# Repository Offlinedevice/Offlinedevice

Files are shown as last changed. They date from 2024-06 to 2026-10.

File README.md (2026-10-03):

# Offline device

Offline device is a hardware device that runs on a Raspberry OS (Linux based) operating system. It can be built with standard components found in the Internet and all the plastic parts can be printed on a 3D-printer.

The Graphical User Interface is written in Python 3 (GUIApp.py).

Follow on Nostr: [npub1srsejseljs22kg580hvcqs3uj3l0fwh8tamhaumdu2gfn3sxs3lskp3chs](https://primal.net/p/npub1srsejseljs22kg580hvcqs3uj3l0fwh8tamhaumdu2gfn3sxs3lskp3chs)

## Features

- [x] Create strong encryption keys offline (GnuPG)
- [x] Use hardware key (NFC Forum Type 2 Tag) for login (optional) 
- [x] Create Bitcoin wallets and Bitcoin Multisig wallets with your own true randomness
- [x] Do offline signing and key management with "Web of trust" -model
- [x] Fully open source (APGLv2)
- [x] Store important files in an encrypted archive (RSA encryption acc. to RFC 4880)
- [x] Encrypt/decrypt and sign files or messages in a secure offline way 
- [x] Decrypt files or messages and check its signature (GnuPG)
- [x] Backup and restore function, including complete system cloning
- [x] Add Bitcoin wallets created from Jade hardware wallet or others for air-gapped transaction signing (BIP84)
- [x] Inheritance package
- [x] Wallet transactions statements 
- [x] Sign Bitcoin wallet messages to prove ovnership of wallet 
- [x] Encrypted password manager
- [x] Generate and manage your own digital ID's (Web of Trust, OpenPGP)
- [x] Generate your own Nostr Keys
- [x] Transfer a Nostr private Key to a Nostr Signing Device
- [x] Validate others digital ID's and keys (standard (RFC 4880)
- [x] Store Bolt cards data for accessing load links (lighning Bitcoin), programming and resetting cards
- [x] Option for strong password generation (also with user entropy)

## Using the Offine device

Connect the Offline device with cables to a monitor, a keyboard and a mouse. It supports multiple account on the same device. Import or generate GPG keys without being connected to the Internet. During setup a backup USB- device is created. The Offline device facilitates complete privacy and unbreakable encryption for sensitive data and also provides a mechanism for securely send and receive data over the Internet. Others features include Bitcoin wallet generation/storage and transaction signing.

### Guides

* [Getting started guide](https://github.com/Offlinedevice/Offlinedevice/blob/057806e96a671aa06b3eac34bdbc17a77e54d67b/help/getstartedHelp.txt)
* [GPG guide](https://github.com/Offlinedevice/Offlinedevice/blob/e34fb841eac5e7634a74db3f75f62b0f8ab91fca/help/gpgHelp.txt)
* [Yubikey guide](https://github.com/Offlinedevice/project/blob/291037e6e33de97521e22a7abb742123ab7c2843/help/yubikeyHelp.txt)
* [Secure archive guide](https://github.com/Offlinedevice/project/blob/291037e6e33de97521e22a7abb742123ab7c2843/help/securearchiveHelp.txt)
* [Digital ID guide](https://github.com/Offlinedevice/project/blob/291037e6e33de97521e22a7abb742123ab7c2843/help/digitalIDHelp.txt)
* [Bolt card guide](https://github.com/Offlinedevice/Offlinedevice/blob/e34fb841eac5e7634a74db3f75f62b0f8ab91fca/help/boltcardHelp.txt)

## Start here

### Build hardware
Build the Offline device using common parts. See [Getting started guide](https://github.com/Offlinedevice/Offlinedevice/blob/057806e96a671aa06b3eac34bdbc17a77e54d67b/help/getstartedHelp.txt)

### 3D- print parts 
Print the plastic parts you need (for the Pi2W version):
* [Base part](https://github.com/Offlinedevice/Offlinedevice/blob/924e57b3c216d11b1677c1a1f53b54e1da3e4c15/3D/PiZero2W/case/PIzeroBoxRoundedCamera-Body.stl)
* [Lid for build with camera model 1/2](https://github.com/Offlinedevice/Offlinedevice/blob/924e57b3c216d11b1677c1a1f53b54e1da3e4c15/3D/PiZero2W/case/LidPIzeroBoxCamera1_and_2_RFID_high-Body.stl)
* [Alt. lid for camera model 3 (12 MP and auto focus lens)](https://github.com/Offlinedevice/Offlinedevice/blob/924e57b3c216d11b1677c1a1f53b54e1da3e4c15/3D/PiZero2W/case/LidPIzeroBoxCamera3_RFID_high-Body.stl)
* [LED guide](https://github.com/Offlinedevice/Offlinedevice/blob/924e57b3c216d11b1677c1a1f53b54e1da3e4c15/3D/PiZero2W/case/LEDguide_high-Body.stl)

See also the folder for other featured 3D- parts (such as the Pi 5).

For printing the Docking station (Raspberry Pi Zero 2W) check out the 3D- files [here](https://github.com/Offlinedevice/Offlinedevice/tree/924e57b3c216d11b1677c1a1f53b54e1da3e4c15/3D/PiZero2W/Dock) and for Pi 5 [here](https://github.com/Offlinedevice/Offlinedevice/tree/924e57b3c216d11b1677c1a1f53b54e1da3e4c15/3D/Pi5/Dock).

### Download and burn image
Download the latest full image and verify it with the corresponding signature. Select the one suitable for your system. Latest update files are found [here](https://github.com/Offlinedevice/Offlinedevice/tree/main/code/GUIApp0_5_7).
* [Raspberry Pi 2 W Image (1,57 gb)](https://www.mediafire.com/file/e7imedgw5ff8n8o/GUIApp0_5_8_Pi2W.img.gz/file)
* [Raspberry Pi 2 W Image Signature](https://www.mediafire.com/file/aozdl05zw8l33cv/GUIApp0_5_8_Pi2W.img.gz.sig/file)
* [Raspberry Pi 5 Image (2,38 gb)](https://www.mediafire.com/file/ete95xyzsxav7um/GUIApp0_5_8_Pi5.img.gz/file) 
* [Raspberry Pi 5 Image Signature](https://www.mediafire.com/file/gw801u4gvd1emua/GUIApp0_5_8_Pi5.img.gz.sig/file)
 
Make sure you have the correct public key (see below) imported to your local keychain. Then place the two downloaded files (the signature and the image) in the same directory and run command: gpg --verify signature_files_name.sig image_files_name.img.gz (insert the real name for the files..).

Then burn it to a microSD-card (min 32 gb) with BalenaEtcher (recommended) or the Raspberry Pi Imager. Please note that it might be necessary to restart the device after initial power ON for it to start.

### Or, install the software yourself
You can choose to install the operating system, programs and libraries yourself. See details in the "Getting started"- document (not updated). 

## Personalized accounts
Change the look and feel of your account. 

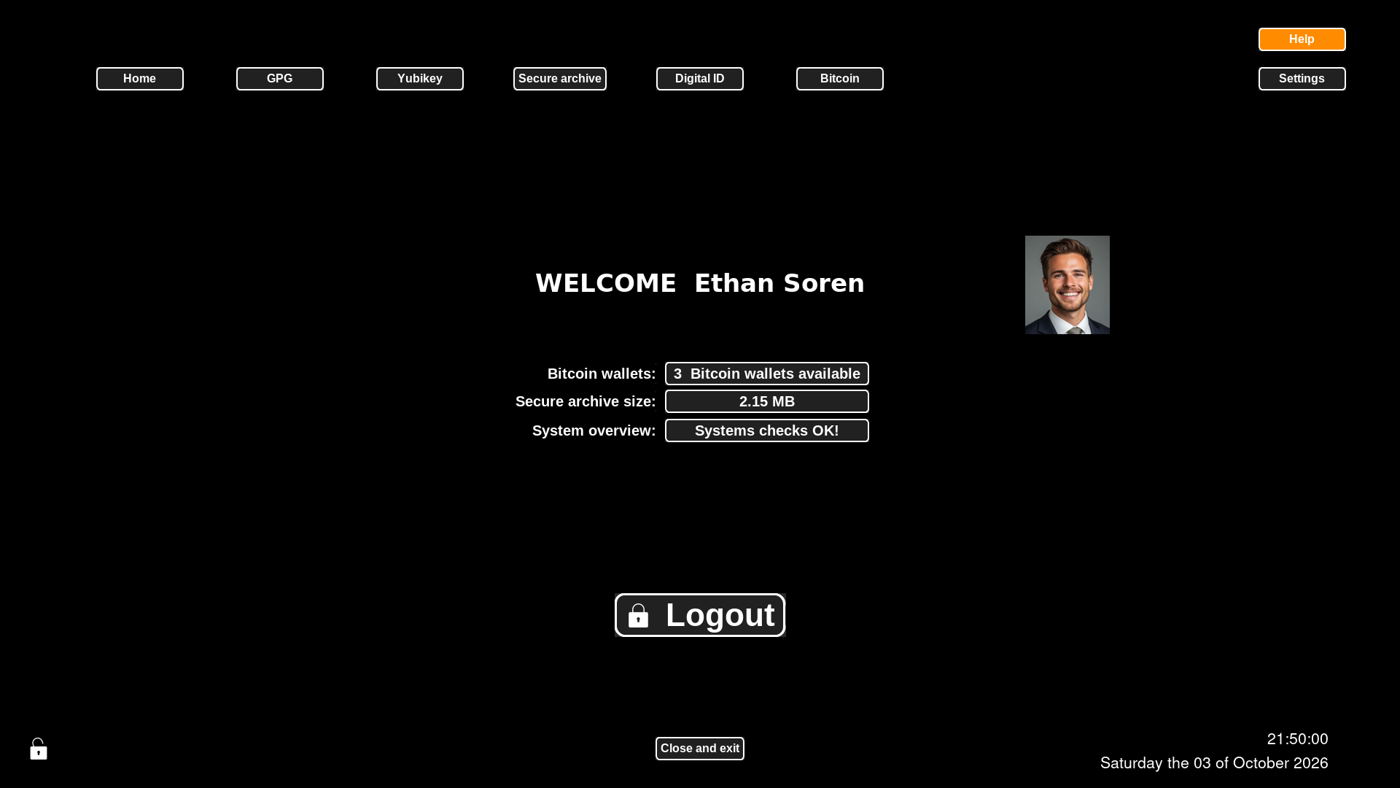
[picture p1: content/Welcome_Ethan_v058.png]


## Manage encryption keys
The device allows you to create your own keys in a secure (and offline) enviroment. Then use and manage the encryption keys on your device. Adding signatures, signing other keys and documents, encrypting and decrypting etc. 

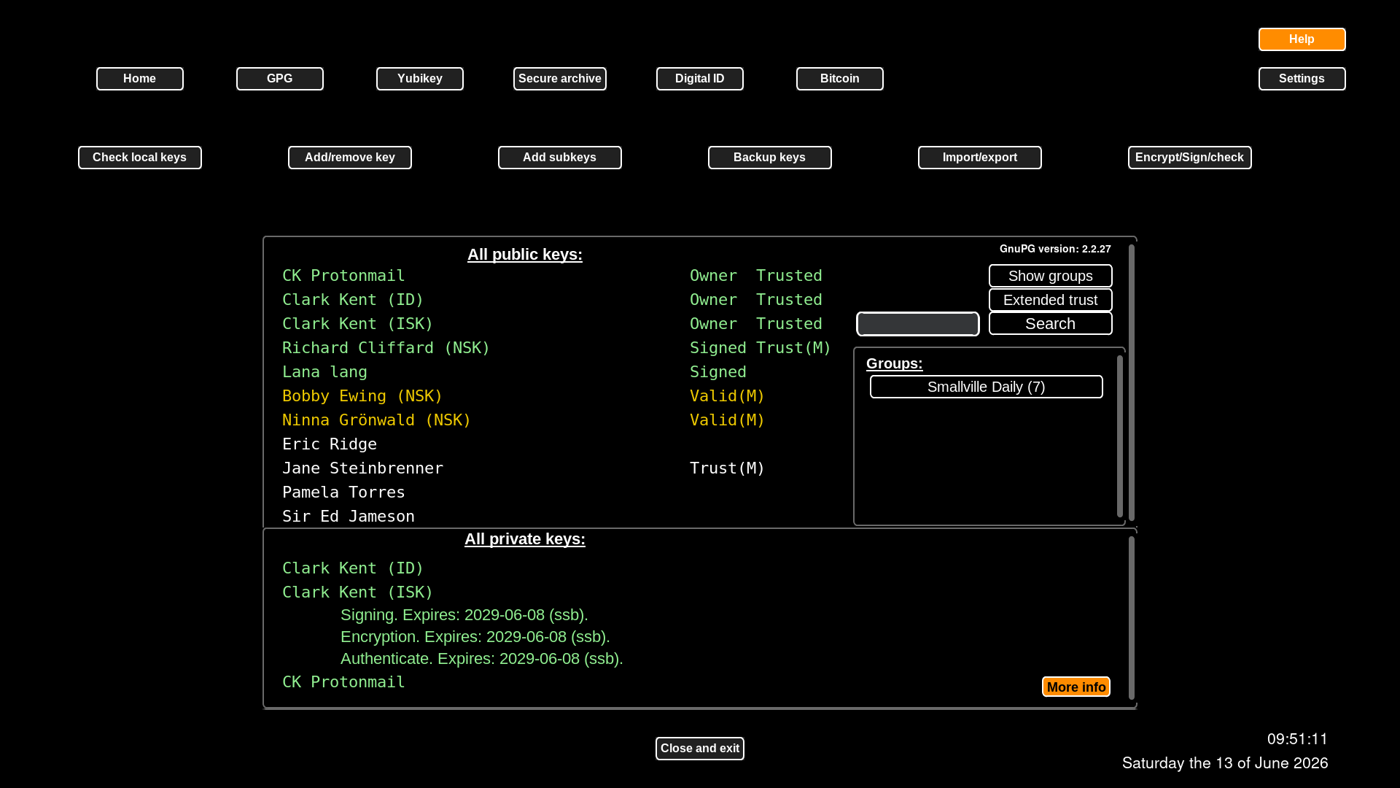
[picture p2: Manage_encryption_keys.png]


## Add and create Bitcoin wallets and Multisig wallets
A wallet can be generated by a trusted hardware wallet such as Blockstream Jade and then inported to get air-gapped functionality while the keys are encrypted on the Offline device. Or, you can create your own keys (seed words) with randomness from dice throws etc.

## Bitcoin Multisig wallets
Create your own multisig signing keys and wallets. Share wallets and signing keys using PGP-encrypted and signed messaging. Also share transactions (request signatures and receive signed transactions back) using PGP-encrypted and signed messaging.

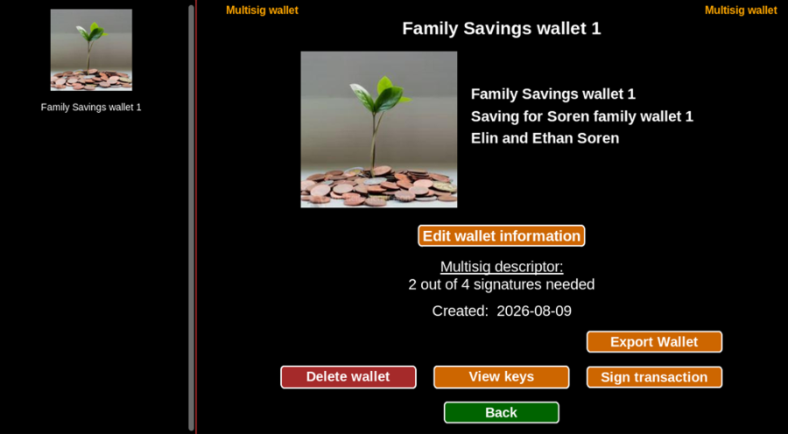
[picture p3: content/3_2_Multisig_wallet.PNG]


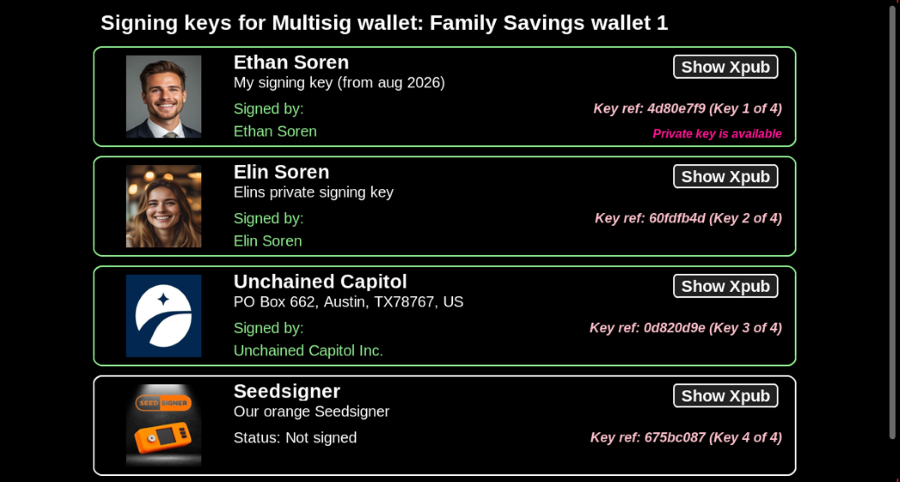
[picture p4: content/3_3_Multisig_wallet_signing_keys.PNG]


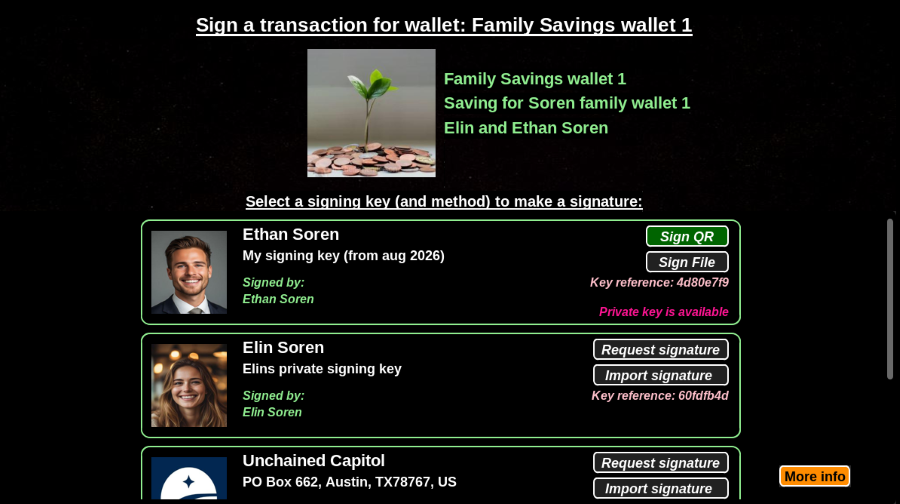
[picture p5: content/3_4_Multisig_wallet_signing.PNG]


## Digital IDs
Controlling your own digital ID is as important as controlling your own digital money. The Offline device gives an easy way to create IDs and encrypted files that can be uploaded to public keyservers around the word. Including picture ID/key and corporate ID. 

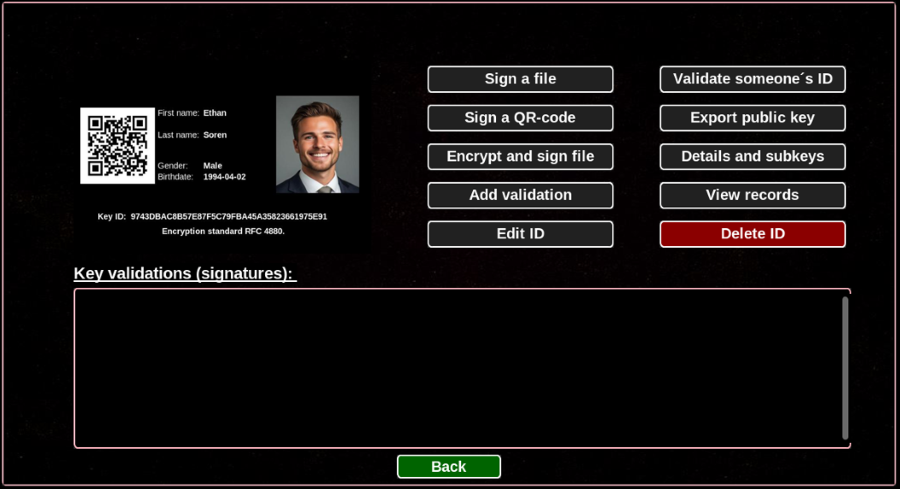
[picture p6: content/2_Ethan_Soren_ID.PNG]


### Update GUI
Make sure you are running the latest graphical interface, GUIApp.py. Download the latest tar- file from the download section and select "settings -> Update software" on the Offline device. 

## Locales
Using a Raspberry Pi keyboard and mouse supports in getting the Locales (correct layout of keys etc.). Always set the correct time and date before staring to use the device. This is important for encryption key generation and date/time stamps. 

## Release + Commit Verification
All releases and commits as of June 28, 2024 are signed by key [BEF873B4691EB2C24E399445FE86F26704C3F74APubKey.asc](https://github.com/Offlinedevice/Offlinedevice/blob/159a1fd89408b5ca1548024ed3b90ddb94b2da3f/code/BEF873B4691EB2C24E399445FE86F26704C3F74APubKey.asc).

### Past Keys
None.

## Donations
If you'd like to help us with the cost of running the Offline device project you can send a payment to us via our BTC address bc1qd0ufcz2xptanlgj2xagzpz46cqdwkvlu69m2vs.

Thank you.

## License

Distributed under the GNU Affero General Public License (AGPL v2). See [LICENSE file](LICENSE).

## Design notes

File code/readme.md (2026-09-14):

## Code for Raspberry Pi 2 W and Raspberry Pi 5:
### Raspberry Pi Zero 2 W configuration:
 - Raspberry Pi Zero 2W
 - RTC DS1307
 - RC522 RFID module
 - Pi camera module 1, 2 or 3

### Wiring schematics Raspberry Pi Zero 2 W:
Make sure to use the correct Lid as the camera modules differ in height. Use 2 mm screws with the right lenght. 

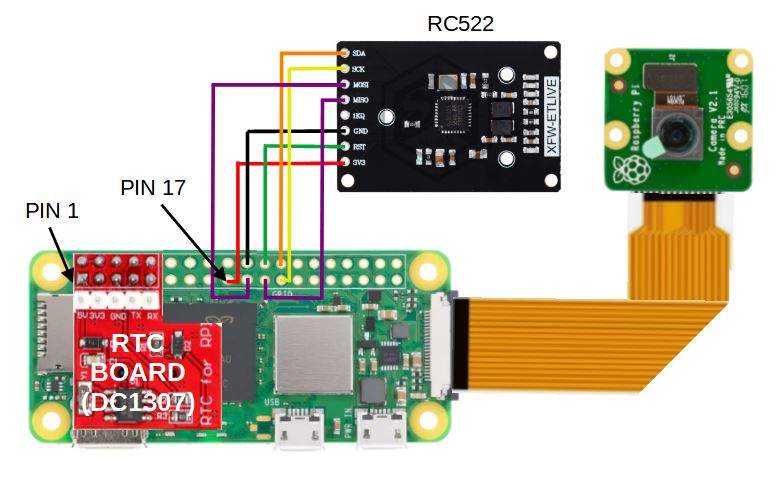
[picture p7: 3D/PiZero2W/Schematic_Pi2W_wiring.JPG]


### Raspberry Pi 5 configuration:
 - Raspberry Pi 5 (min 1 GB RAM)
 - RTC battery
 - PN532 RFID module V3
 - 5V 3007 Fan PWM Speed Adjustable CPU Cooling fan
 - LED, RGB model WS2812D
 - Cable for camera, MIPI 22-pin to FPC 15-pin (CSI), 8 cm
 - Lithium RTC clock battery, 3 V
 - Pi camera module 1, 2 or 3

 - ### Wiring schematics Raspberry Pi 5
Make sure to use the correct Lid as the camera modules differ in height. Use 2 mm screws with the right lenght.

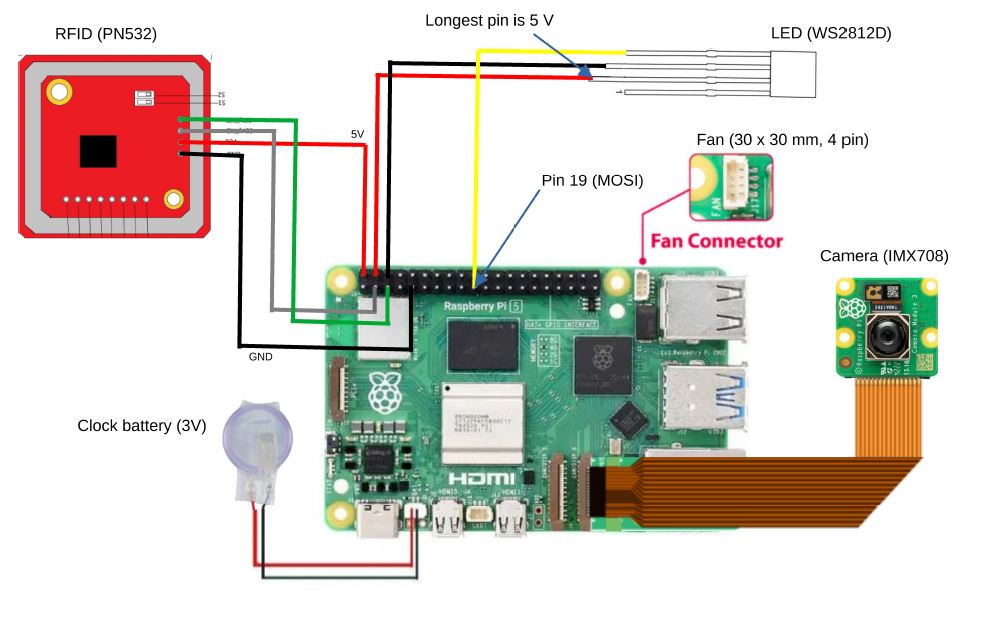
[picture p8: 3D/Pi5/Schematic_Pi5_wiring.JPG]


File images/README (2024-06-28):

# Files that need to be in Offline devices directory /home/user1/venvpython/images.

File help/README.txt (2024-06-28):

# All help files for the Offline device.

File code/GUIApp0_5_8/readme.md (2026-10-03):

## GUI app for the Offline device. This release can be installed using the following:

### For Raspberry Pi Zero 2 W: GUIApp_0_5_8_Pi2W.tar.gz. The full Image (v0.5.7) or later needs to installed.
### For Raspberry Pi 5: GUIApp_0_5_8_Pi5.tar.gz. The full Image (v0.5.7) or later needs to installed.
##

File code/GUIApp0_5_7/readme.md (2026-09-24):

## GUI app for the Offline device. This release can be installed using the following:

### For Raspberry Pi Zero 2 W: GUIApp_0_5_7_Pi2W.tar.gz. The full Image (v0.5.7) or later needs to installed.
### For Raspberry Pi 5: GUIApp_0_5_7_Pi5.tar.gz. The full Image (v0.5.7) or later needs to installed.
##

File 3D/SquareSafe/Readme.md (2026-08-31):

## Hardware safe for Offline device and/or other devices:
Safe details:
 - Based on a padlock with extra long shackle such as ABUS 64ti/50hb60-150.
 - Internal plastic parts are printed using high strenght material such as PETG-CF or PA6-CF20 etc for best performance.
 - Internal storage compartment have four options: two for a vertical mounted safes and two for horizontally mounted safes.
 - See also assembly schematics and technical drawings for more details. 

## Using a hardware safe
The safe can't protect the stored content from heat during a fire or from a thief using heavy equipment or mashinery. Instead it protects from manipulation (planting key loggers and other spyware).

Outer case can be aluminium, steel or simply 3D printed plasic (see [SquareSafe tube drawing](https://github.com/Offlinedevice/Offlinedevice/blob/ef2869bde410553fd2b8278cb0528959d3572997/3D/SquareSafe/SquareSafe%20tube%20drawing.pdf)).

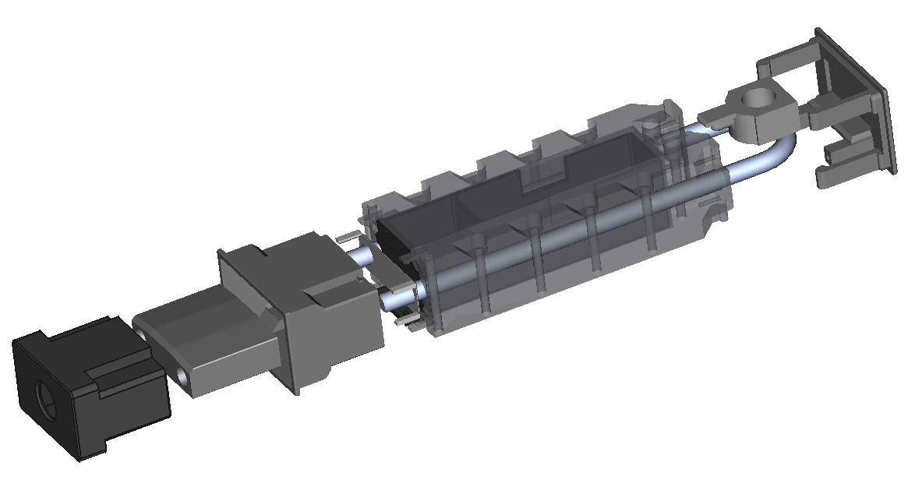
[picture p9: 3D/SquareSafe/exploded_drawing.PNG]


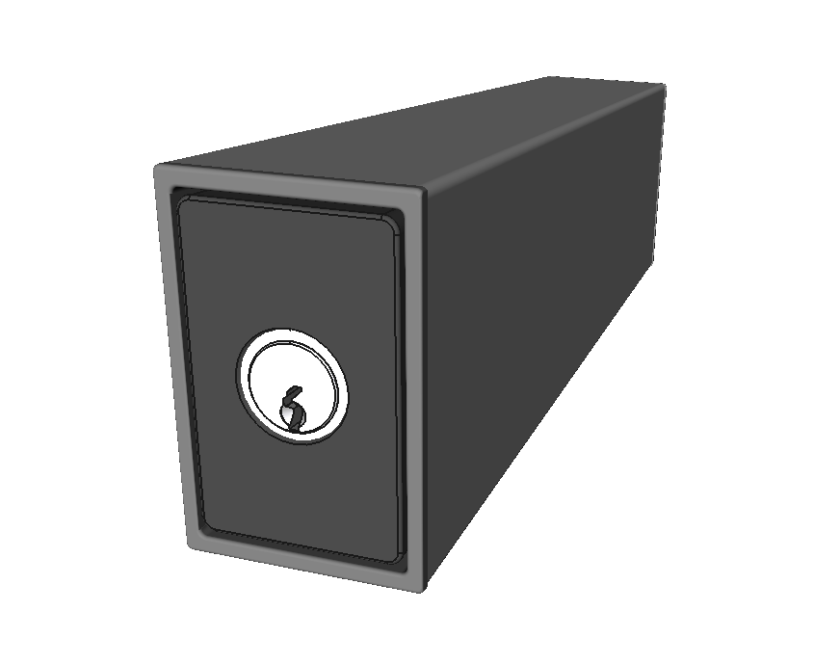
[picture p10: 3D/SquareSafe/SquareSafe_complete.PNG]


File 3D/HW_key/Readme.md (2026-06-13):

## Hardware key for Offline device:
Key contains:
 - NTAG210q or similar NFC Forum Type 2 tag (min 48 bytes of memory and max dimensions 12 x 19 mm)
 - LED-chip with antenna for luminate when in proximity to RF-field.

## Using the HW-key to unlock account
Select add HW-key during account creation (or later on). Create the new account with a truly random base58 password (select "use strong password" and follwo the instructions). 
Then create a truly random salt (secret) also select a easy to remember PIN. Hold the key over the device to write the salt/secret to NTAG-memory. 
Now when the account is encrypted (during shudown/logout) both the HW-keys and the "strong password" will be use to encrypt your secret data. 
So during next login you can use the either the long base58 password the you you created with your own randomness (more difficult) or you can use one of your HW-keys by holding it close to the reader and type in your PIN (if any). 
The passphrase used to decrypt the account is then hashed (calculated) from the salt+keys serial number+PIN using a proof-of-work algorithm.

If using LED-chip inside key use transparent PETG-filament or similar for a nice effect.
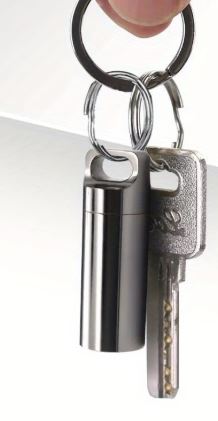
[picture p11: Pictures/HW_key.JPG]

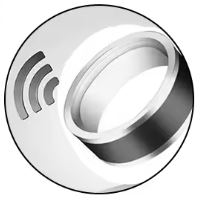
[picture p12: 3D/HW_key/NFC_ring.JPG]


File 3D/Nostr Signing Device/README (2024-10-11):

# Files for printing a Nostr Signing Device (NSD), using a 3D- printer.

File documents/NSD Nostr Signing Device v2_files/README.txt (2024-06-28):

# All files that goes in directory "Documents" on the Offline device.

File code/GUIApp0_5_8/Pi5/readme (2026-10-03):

A full image that can be burned to a microSD- card with minimum 32 gb storage as linked on the Project main page. Note, the image is only operational with specified hardware: Raspberry Pi 5, Rechargeable real time clock battery, RFID module PN532 (optional) and a PI camera module (ov5647/imx219/imx708)
Update to version 0.5.8 can be done with GUIApp0_5_8_Pi5.tar.gz (needs the the full image version 0.5.7 or later to be installed first).

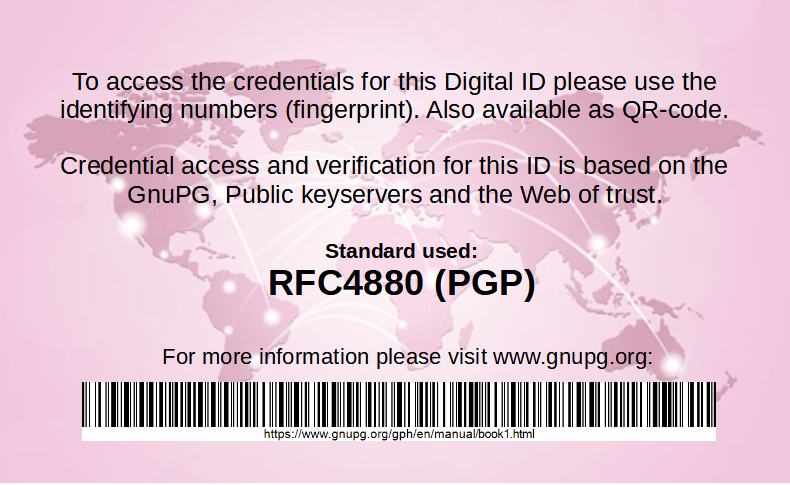
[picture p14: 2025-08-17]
images/ID_map_back.png

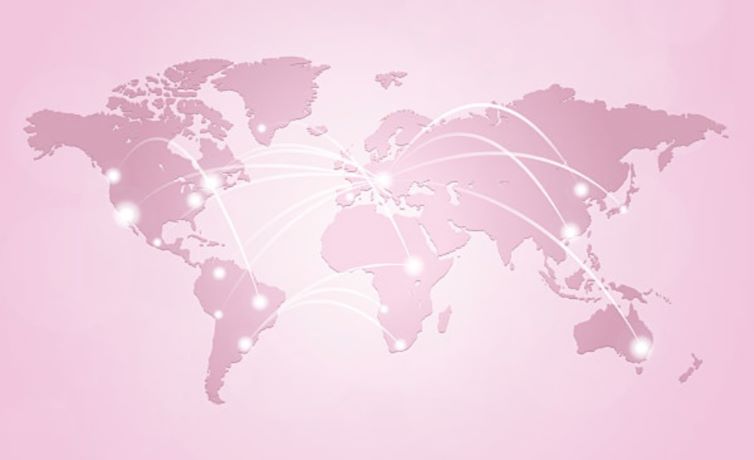
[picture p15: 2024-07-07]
images/ID_map.jpg

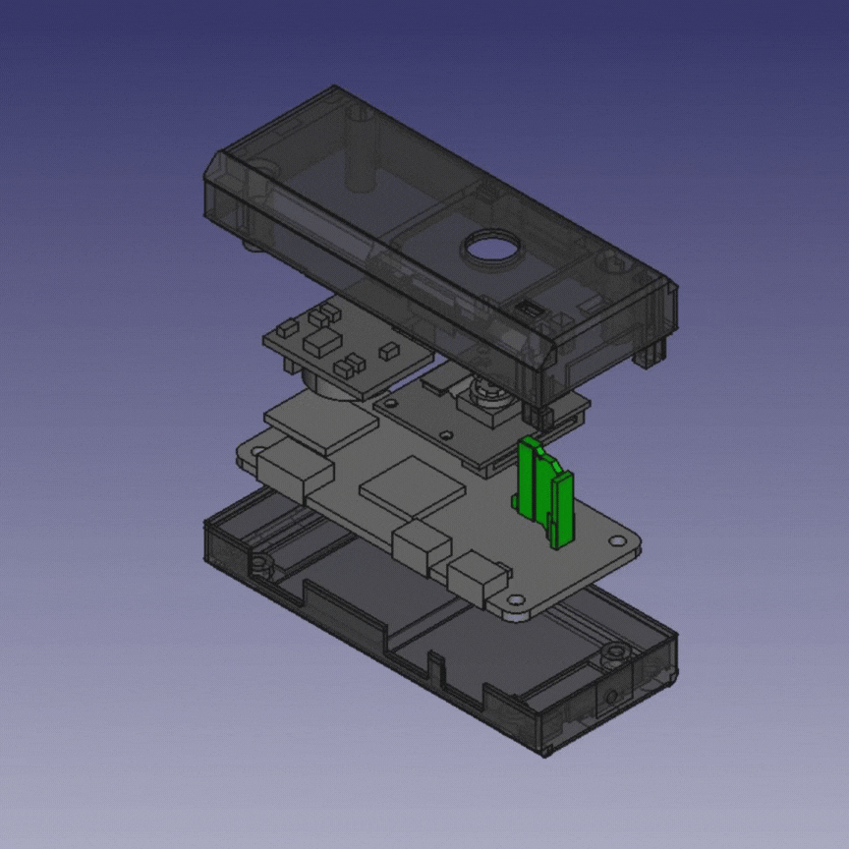
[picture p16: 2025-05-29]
OfflineDevice3D.gif

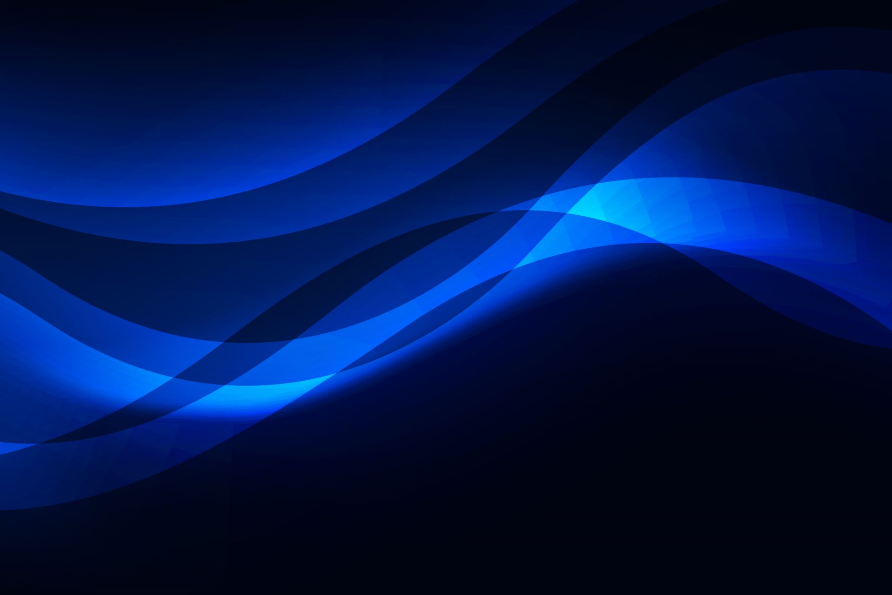
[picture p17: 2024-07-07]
images/blue.jpg

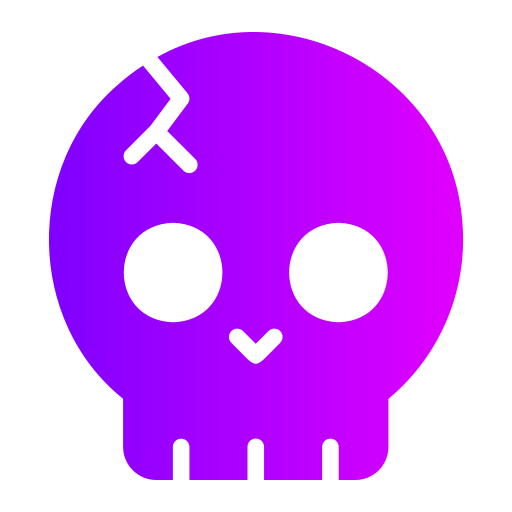
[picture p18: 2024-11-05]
Pictures/user_skull.png

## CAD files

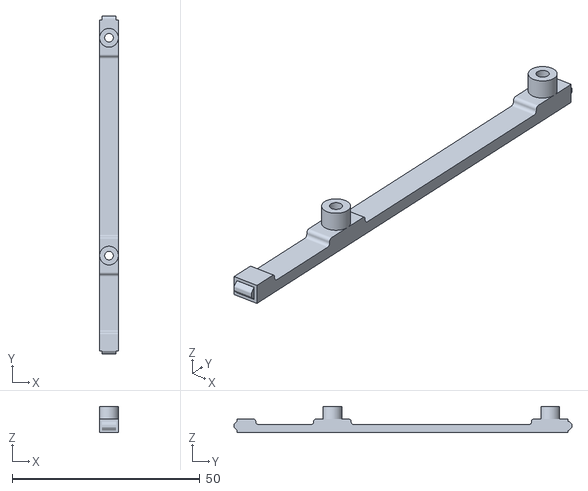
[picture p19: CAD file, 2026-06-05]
3D/Pi5/Case/Pi5_bottom_Full_case_SSD_PIN-Body.stl
5.00 x 90.0 x 7.00

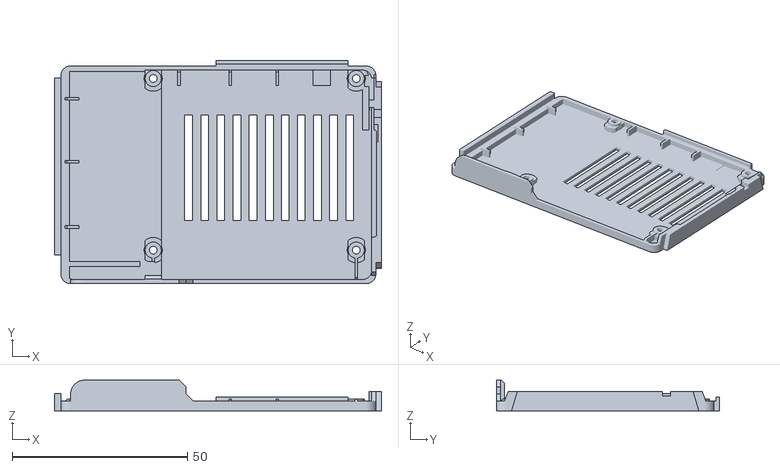
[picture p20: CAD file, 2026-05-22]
3D/Pi5/Case/Pi5_bottom_Full_case-Body.stl
93.4 x 63.8 x 8.80

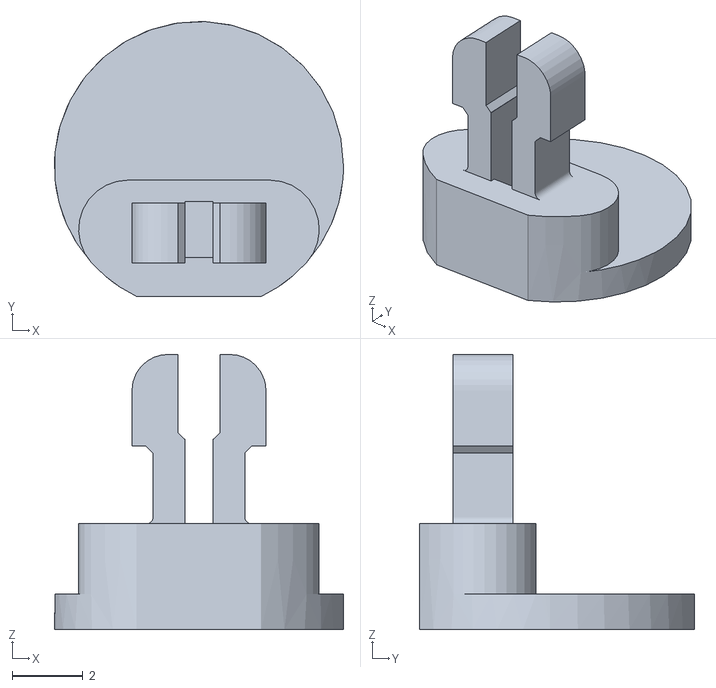
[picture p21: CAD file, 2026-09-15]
3D/HW_key/HW_PIN_SMALL_CAP-Body.stl
8.20 x 7.80 x 7.80

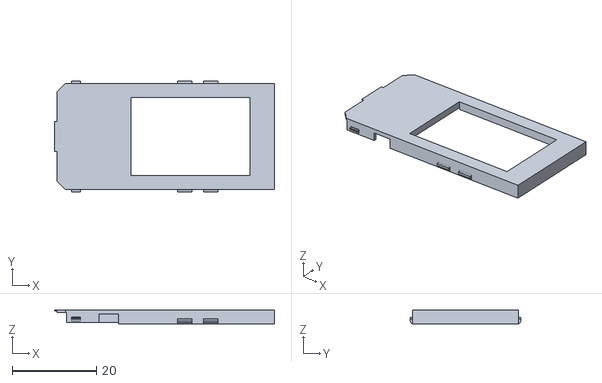
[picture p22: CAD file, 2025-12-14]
3D/Nostr Signing Device/NostrSignerLidMini_v3-Body.stl
52.2 x 26.4 x 3.40

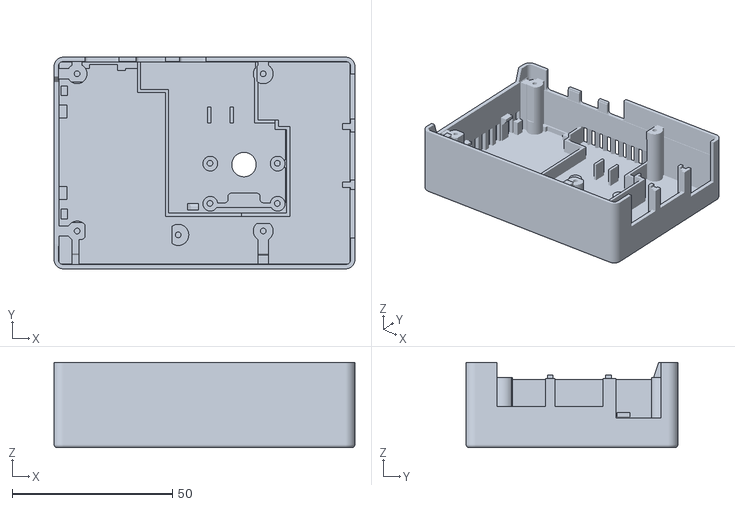
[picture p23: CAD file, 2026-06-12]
3D/Pi5/Case/Case_Pi5_12MP_Double_vent_fan_no_LED-Body002.stl
93.8 x 66.0 x 26.6

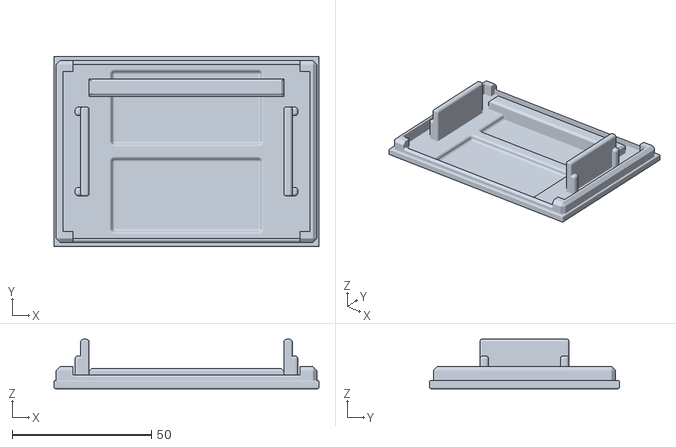
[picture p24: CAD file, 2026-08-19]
3D/Pi5/Dock/Dock_dummy_lid_5_with_trim-Body.stl
95.2 x 68.2 x 17.8

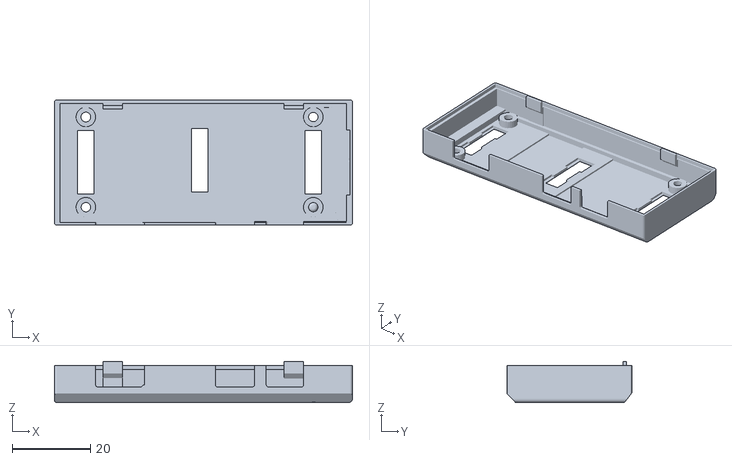
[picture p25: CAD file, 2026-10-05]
3D/PiZero2W/case/PIzeroBoxRoundedCamera_with_trim-Body.stl
76.0 x 32.0 x 10.5

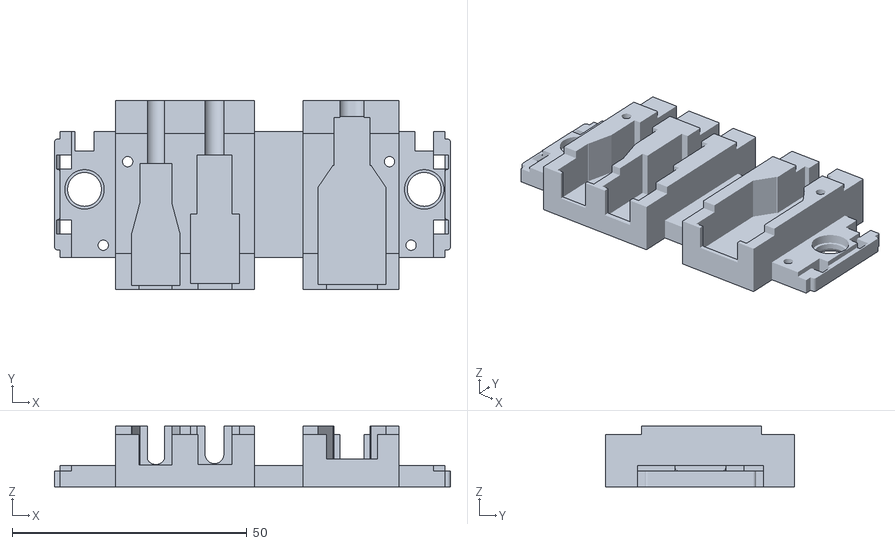
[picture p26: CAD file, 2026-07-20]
3D/PiZero2W/Dock/Cable_holder_with_trim-Body.stl
84.4 x 40.2 x 13.0

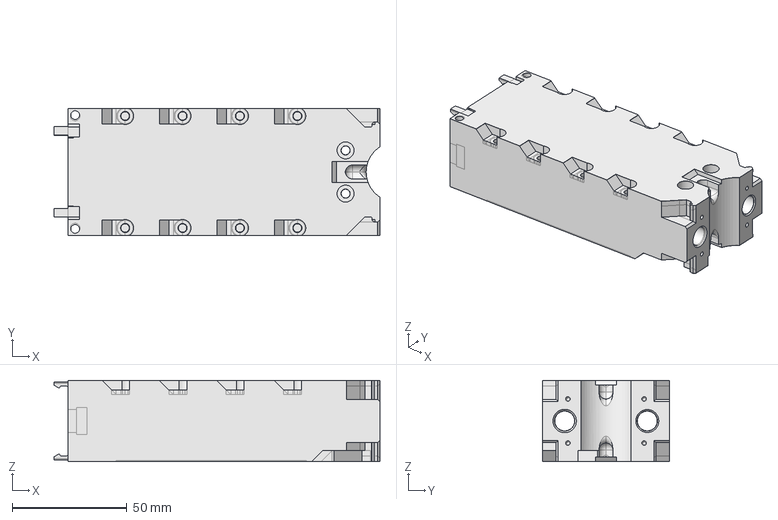
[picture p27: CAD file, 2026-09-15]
3D/SquareSafe/InsideBox-Body.step
142.0 x 55.2 x 35.5 mm

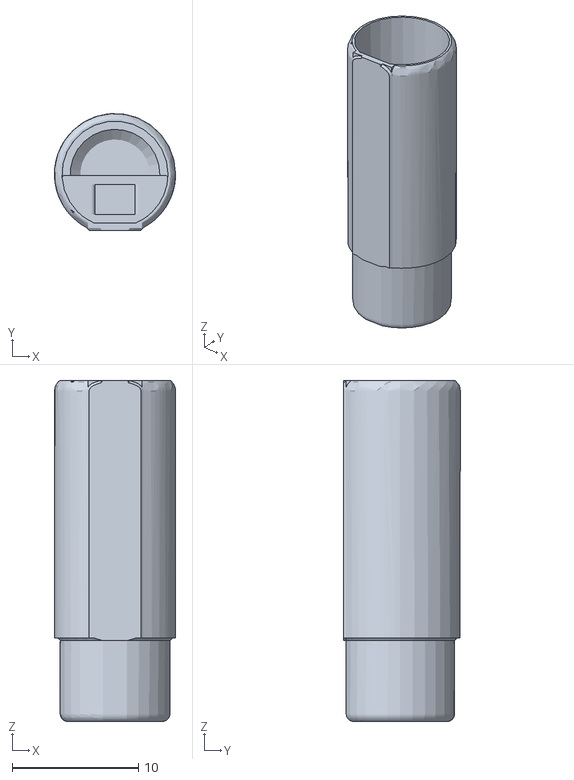
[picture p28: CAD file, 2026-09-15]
3D/HW_key/HW_PIN_SMALL-Body.stl
9.60 x 9.24 x 27.0

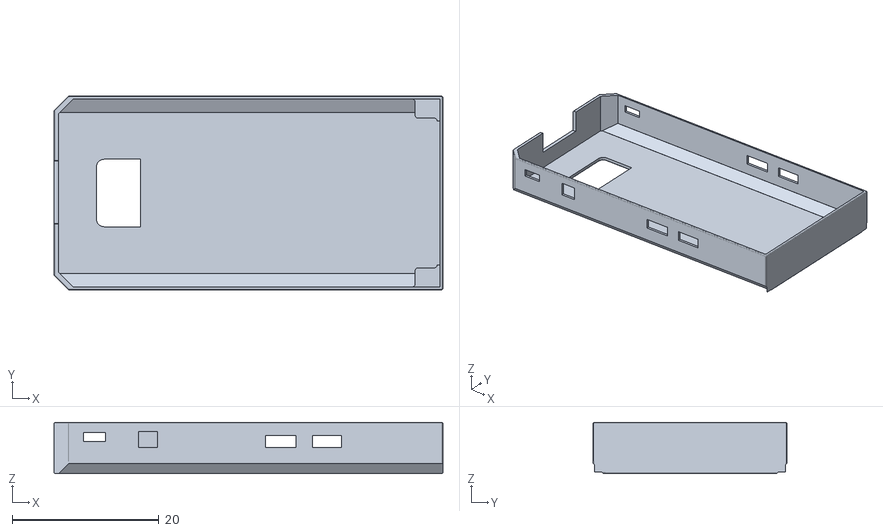
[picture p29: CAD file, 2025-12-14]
3D/Nostr Signing Device/NostrSignerBaseMini_v3-Body.stl
53.0 x 26.4 x 7.00

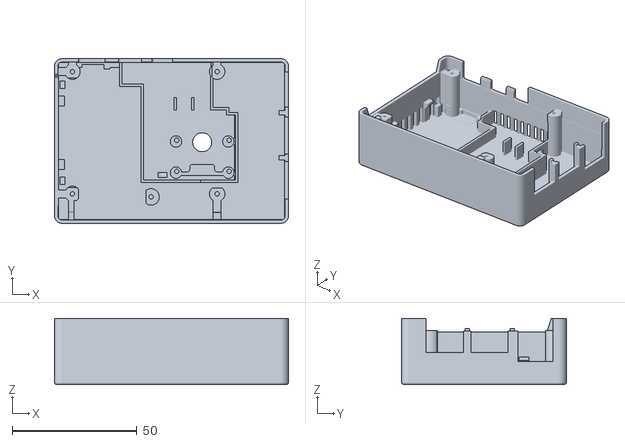
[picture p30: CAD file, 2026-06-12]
3D/Pi5/Case/Case_Pi5_5MP_Double_vent_fan_no_LED-Body002.stl
93.8 x 66.0 x 26.6

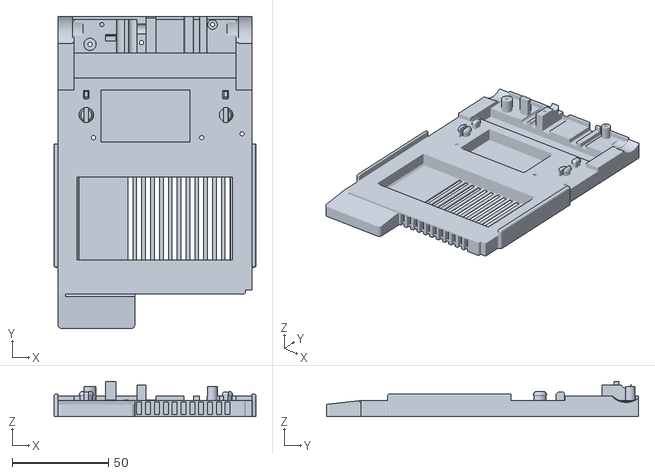
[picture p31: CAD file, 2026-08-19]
3D/Pi5/Dock/Dock_bottom_5_vent-Body.stl
105.0 x 162.2 x 18.4

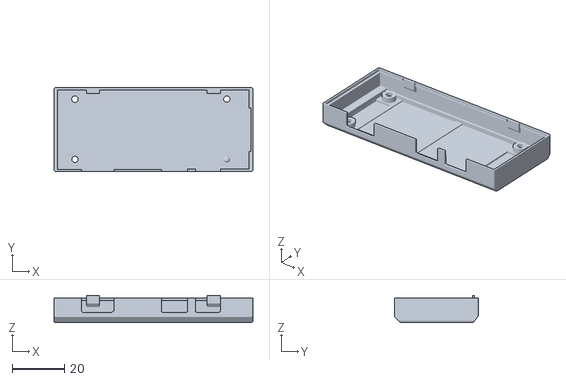
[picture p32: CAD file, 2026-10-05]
3D/PiZero2W/case/PIzeroBoxRoundedCamera-Body.stl
76.0 x 32.0 x 10.5

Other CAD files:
3D/PiZero2W/Dock/Dock_lever_trim_mid-Body.stl
3D/SquareSafe/BackStop-Body.stl
3D/HW_key/NFCKeyCap_LED_v2-Body.stl
3D/Pi5/Dock/Dock_bottom_5_SSD_vent-Body.stl
3D/HW_key/NFCKeyBase_LED_v2-Body.stl
3D/Pi5/Case/Case_Pi5_12MP_Double_vent_fan-Body002.stl
3D/Pi5/Case/Case_Pi5_5MP_Double_vent_fan-Body002.stl
3D/Pi5/Case/Case_Pi5_fixing_bridge-Body002.stl
3D/Pi5/Case/Fan_cover_v2-Body.stl
3D/Pi5/Case/Pi5_Bottom_LED_guide-Body.stl
3D/Pi5/Dock/Cable_holder_5_15W-Body.stl
3D/Pi5/Dock/Cable_holder_5_27W-Body.stl
3D/Pi5/Dock/Dock_dummy_lid_5-Body.stl
3D/Pi5/Dock/Dock_lever_5_v2-Body.stl
3D/Pi5/Dock/Dock_sled_5-Body.stl
3D/Pi5/Dock/Dock_top_5-Body.stl
3D/PiZero2W/Dock/Cable_holder-Body.stl
3D/PiZero2W/Dock/Cable_holder_trim-Body.stl
3D/PiZero2W/Dock/Dock_Pi2W_dummy_lid-Body.stl
3D/PiZero2W/Dock/Dock_Pi2W_dummy_lid_trim-Body.stl
3D/PiZero2W/Dock/Dock_Pi2W_dummy_lid_with_trim-Body.stl
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

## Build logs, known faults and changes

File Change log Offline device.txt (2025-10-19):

Changes for GUIApp.py software for Offline device

2025-07-18:
News in version 0.3.9:
- Air-gapped Bitcoin message signing (proof of wallet ownership).
- Fix for message signing using textfiles.

The worlds first! Use Bitcoin fully Air-gapped: - Air-gapped wallet creation. - Air-gapped transaction signing. - Air-gapped Bitcoin message signing (proof of wallet ownership). 

2025-08-17:
News in version 0.4.0:
- Inheritance package.
- Creating new Bitcoin wallets seeds with dice throws.
- Various improvements for Secure archive, Digital ID's and Bolt cards.

2025-08-28:
News in version 0.4.1:
- Simplified recovery process.
- Simplified account creation.
- Various improvements for Dice wallets, Backups and graphics.
 
2025-08-28:
Version 0.4.1b:
- Patch for fixing issue with creating inheritance package.

2025-09-04:
New in version 0.4.2:
- Option for using strong password (also with users entropy) for:
	- Encryption keys.
	- Inheritance package.
	- Bitcoin wallets.
	- General purpose application.
- Export wallet seed as encrypted and signed message (auto detect when decrypting message).

2025-09-10:
New in version 0.4.3:
- Option for using strong password (also with users entropy) for new account.
- Changed visuals.
- Exception handling.

2025-09-30:
New in version 0.4.4:
- Web-of-trust for keys, encryption and checking signatures/identity/trust.
- Groups for public keys. One-click group actions for importing/exporting keys and for encryption.
- Assign trust, alias and groups when importing keys (also when importing multiple keys at once).
- Auto recovery for Digital ID’s and encryption keys.

2025-10-13:
New in version 0.4.5:
- Key management, new layout with pictures, expire date etc.
- Record keeping for Digital ID’s and keys.
- Updated help texts.

2025-10-19:
New in version 0.4.6:
- Fix for creating new account.
- Fix for recovering account.
- Fix for exporting a public key(s).

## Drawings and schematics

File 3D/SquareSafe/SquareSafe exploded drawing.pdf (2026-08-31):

3

4

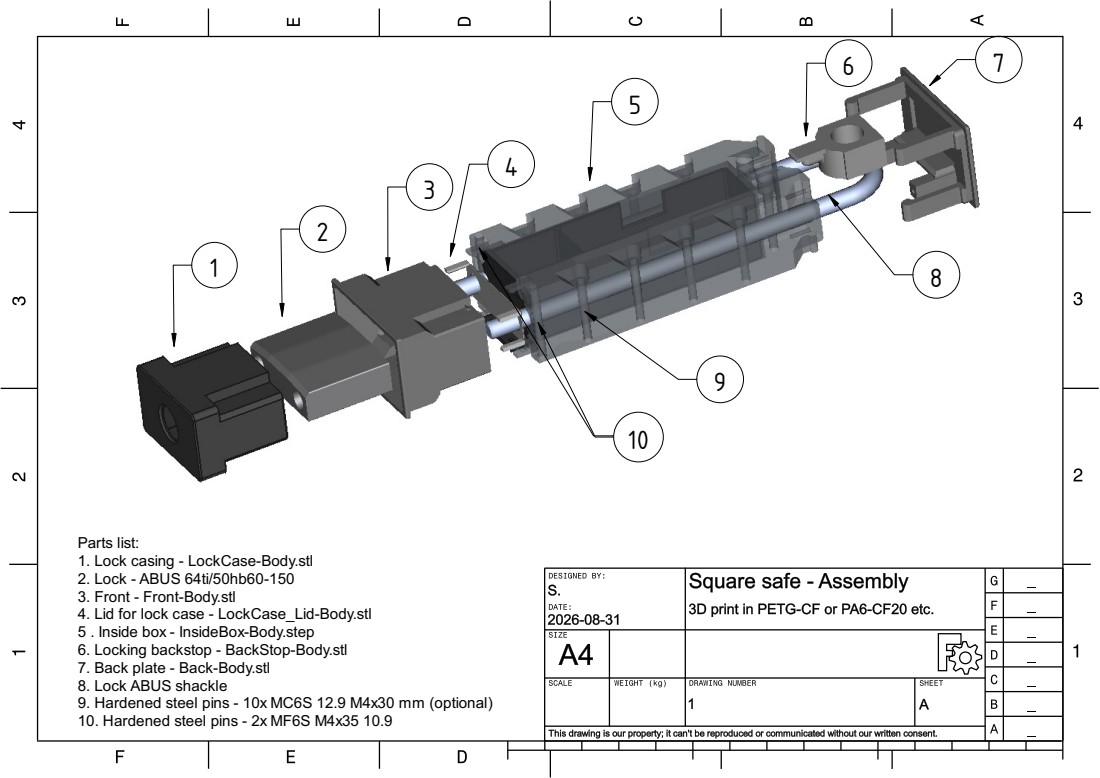
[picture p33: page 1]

Parts list:
1. Lock casing - LockCase-Body.stl
2. Lock - ABUS 64ti/50hb60-150
3. Front - Front-Body.stl
4. Lid for lock case - LockCase_Lid-Body.stl
5 . Inside box - InsideBox-Body.step
6. Locking backstop - BackStop-Body.stl
7. Back plate - Back-Body.stl
8. Lock ABUS shackle
9. Hardened steel pins - 10x MC6S 12.9 M4x30 mm (optional)
10. Hardened steel pins - 2x MF6S M4x35 10.9

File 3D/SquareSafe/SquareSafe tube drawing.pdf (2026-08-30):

2

3

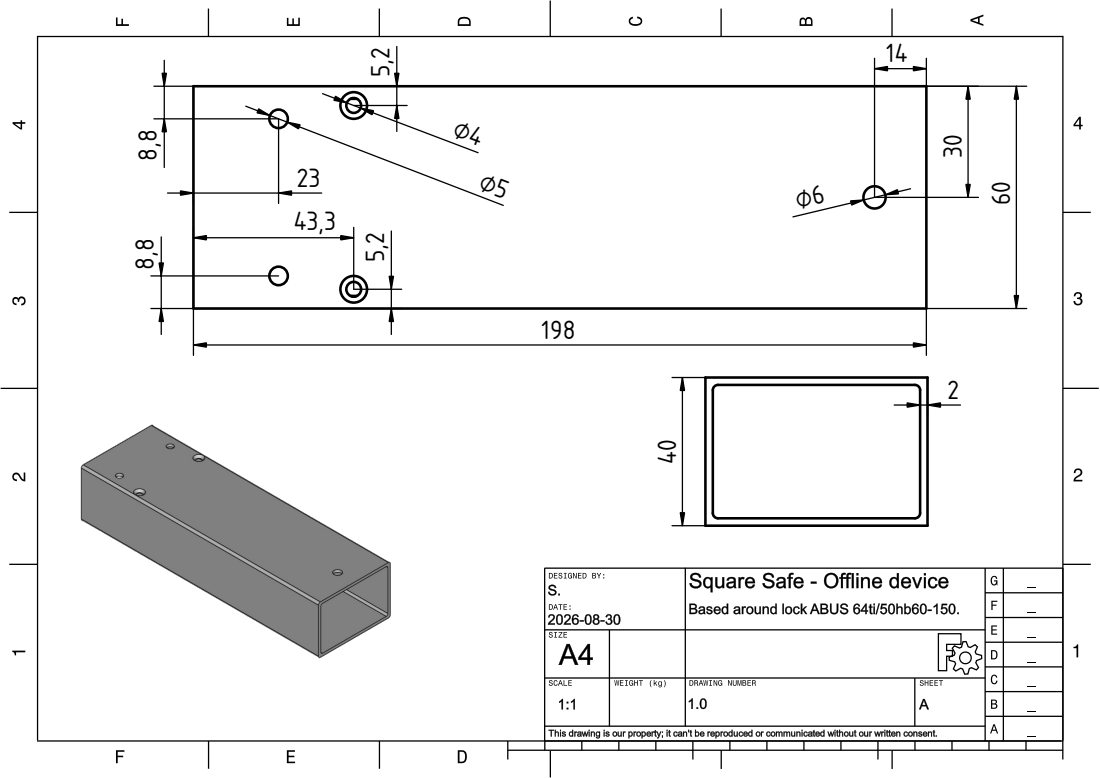
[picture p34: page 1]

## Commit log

2024-06-28 Create README.txt
    Using the help files for the Offline device.
2024-06-30 Update README.md
    Added fingerprint for the signing GPG key.
2024-07-06 Update boltcardHelp.txt
    2024-07-06
2024-07-16 Add files via upload
    Fix.
    [PIzeroBox.stl]
2024-10-11 Update and rename 3D/README to 3D/Nostr Signing Device/README
